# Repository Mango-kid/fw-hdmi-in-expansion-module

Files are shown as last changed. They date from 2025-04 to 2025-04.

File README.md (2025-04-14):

# Description
An HDMI input expansion module for the FW laptop. It utalizes the MS213x. As far as I can tell this is the highest preformance HDMI capture chip avalible that can fit in this package and not require serious thermal considerations. 
- USB3.0
- 100ms or better latency at 1080 in MJPEG mode (glass to glass, capture only will be less)

## Status
- hardware being prototyped and tested

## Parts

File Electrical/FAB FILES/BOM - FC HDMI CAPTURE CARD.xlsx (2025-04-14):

Designator | Qnty | Comment | Footprint | LCSC Part # | Externally Sourced | REMARK
C1,C2,C3,C4,C5,C6,C7,C8,C9,C10,C11,C12,C13,C14,C15,C16,C17,C18,C19,C20,C21,C22,C23,C27,C28,C29 | 26 | 0.1uF | 402
C24,C25 | 2 | 22pF | 402
C26 | 1 | 10uF | 603
C30,C31,C32,C33,C35,C36 | 6 | 22uF | 805 | C45783
C34 | 1 | 1uF | 603
D1 | 1 | LED | 402
D2 | 1 | PMEG1030EH | SOD-123F | C552800
J1 | 1 | HD06-19-RVS-MSMT-TR | HD06-19-RVS-MSMT-TR |  | HD06-19-RVS-MSMT-TR
J2 | 1 | USB-307HE-B-SU | SMD | C309351
L1,L2,L3 | 3 | 2.2uH | 1008 | C36400
R1,R2 | 2 | 4.7k | 402
R3 | 1 | 1.6k | 402
R4 | 1 | 0R | 402
R5 | 1 | 2k | 402
R6 | 1 | 200R | 402
R7,R8 | 2 | 1k | 402
R9 | 1 | 5.1k | 402
R10 | 1 | 100k | 402
R11 | 1 | 680k | 402
R12,R13,R16 | 3 | 150k | 402
R14 | 1 | 470k | 402
R15 | 1 | 180k | 402
U1 | 1 | MS2130 | QFN-64-EP(9x9) | C5905137
U2,U3,U4,U5 | 4 | TPD4E02B04DQA | USON-10(1x2.5) | C106794
U6 | 1 | EA3059 | QFN-24-EP(4x4) | C111586
U8 | 1 | W25Q16JVUXIQ | USON-8-EP(2x3) | C2843335
Y1 | 1 | Q22FA12800489 | Crystal:Crystal_SMD_2016-4Pin_2.0x1.6mm | C255882

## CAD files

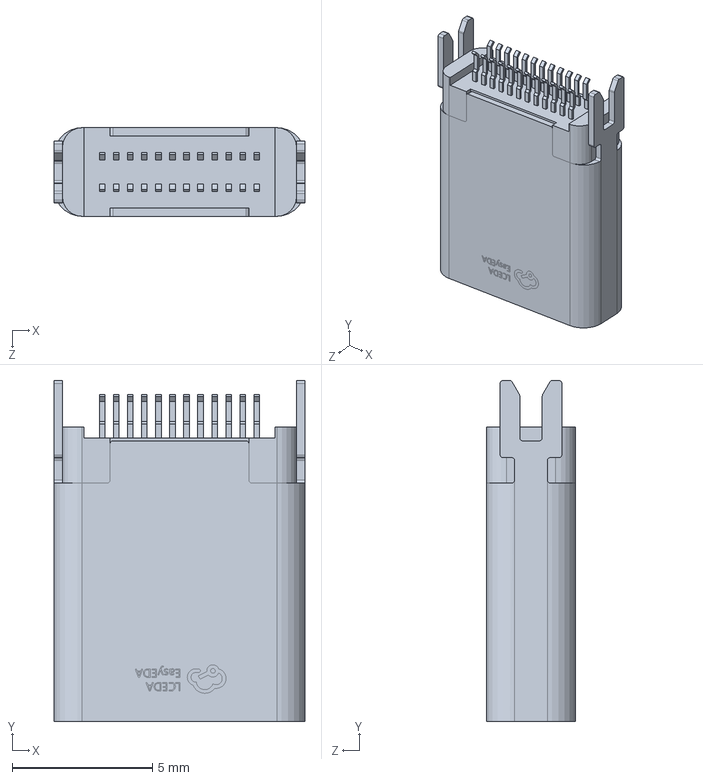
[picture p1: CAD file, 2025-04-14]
Electrical/FOOTPRINTS/3D MODELS/3D_PCB1_2025-03-29.step.SLDASM
8.94 x 12.2 x 3.16 mm

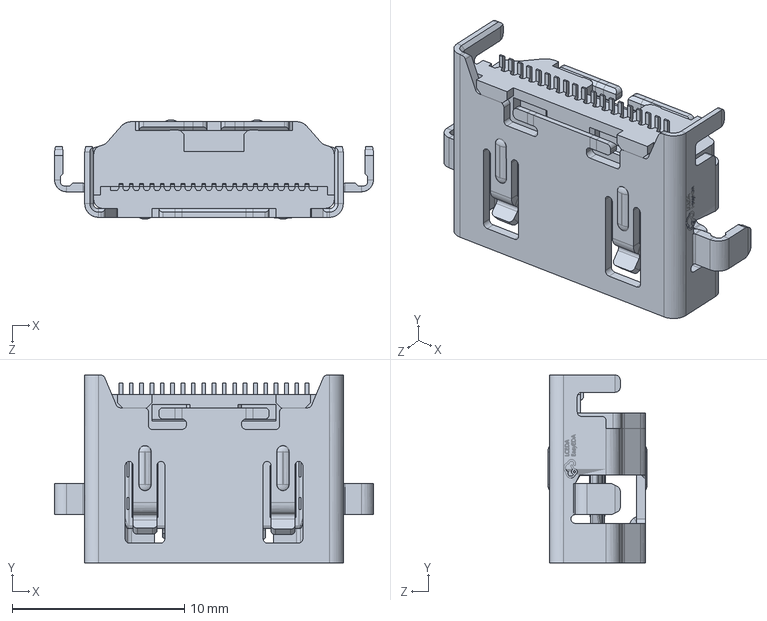
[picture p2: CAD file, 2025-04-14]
Electrical/FOOTPRINTS/3D MODELS/3D_PCB1_2025-03-29(2).step.SLDASM
18.5 x 10.9 x 5.75 mm

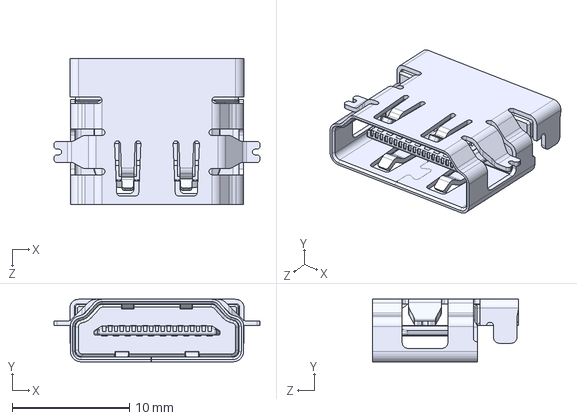
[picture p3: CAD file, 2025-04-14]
Electrical/FOOTPRINTS/3D MODELS/Same_Sky_HD06-19-RVS-MSMT-TR.step
17.6 x 5.36 x 12.5 mm

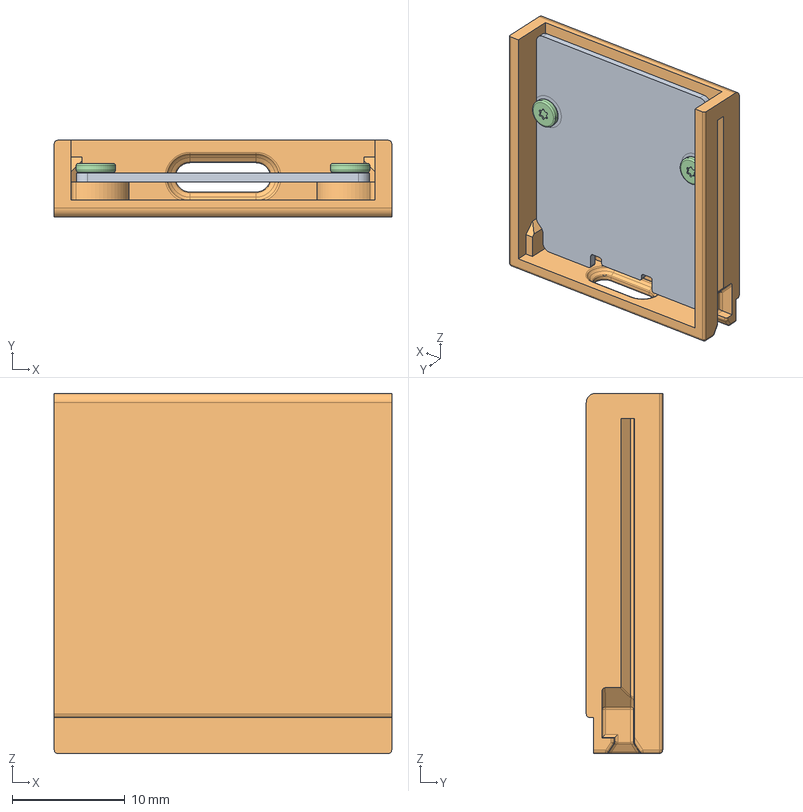
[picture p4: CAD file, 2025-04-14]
Electrical/FOOTPRINTS/3D MODELS/ExpansionCard_ThreadedInsert.stp
30.0 x 6.80 x 32.0 mm
FW_EXP_1USBC_FRAME_CLIP_BC_229_
NUT_M2X1-6L_2 x 2
STAR_SCREW_M2X3L_298_2 x 2

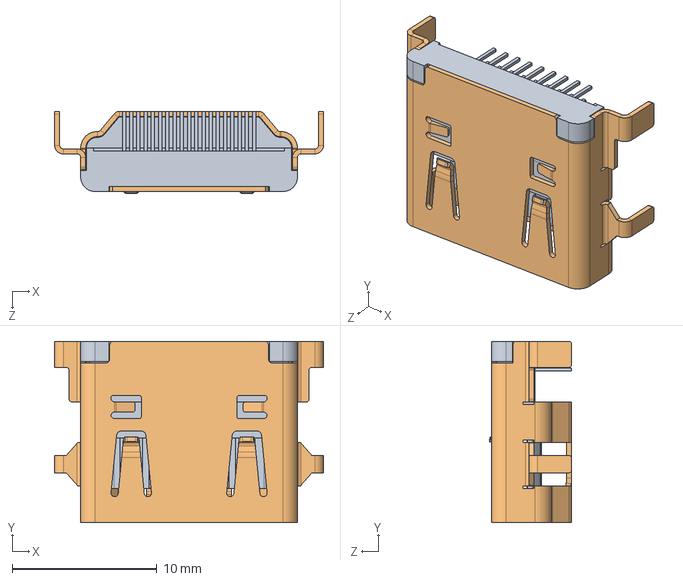
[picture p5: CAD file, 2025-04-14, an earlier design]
Electrical/FOOTPRINTS/3D MODELS/3D_PCB1_2025-03-29(1).STEP
18.6 x 12.5 x 5.70 mm

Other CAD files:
Electrical/FOOTPRINTS/3D MODELS/Board~sIiM.step.SLDPRT
Electrical/FOOTPRINTS/3D MODELS/3D_PCB1_2025-03-29.STEP
Electrical/FOOTPRINTS/3D MODELS/3D_PCB1_2025-03-29(2).STEP

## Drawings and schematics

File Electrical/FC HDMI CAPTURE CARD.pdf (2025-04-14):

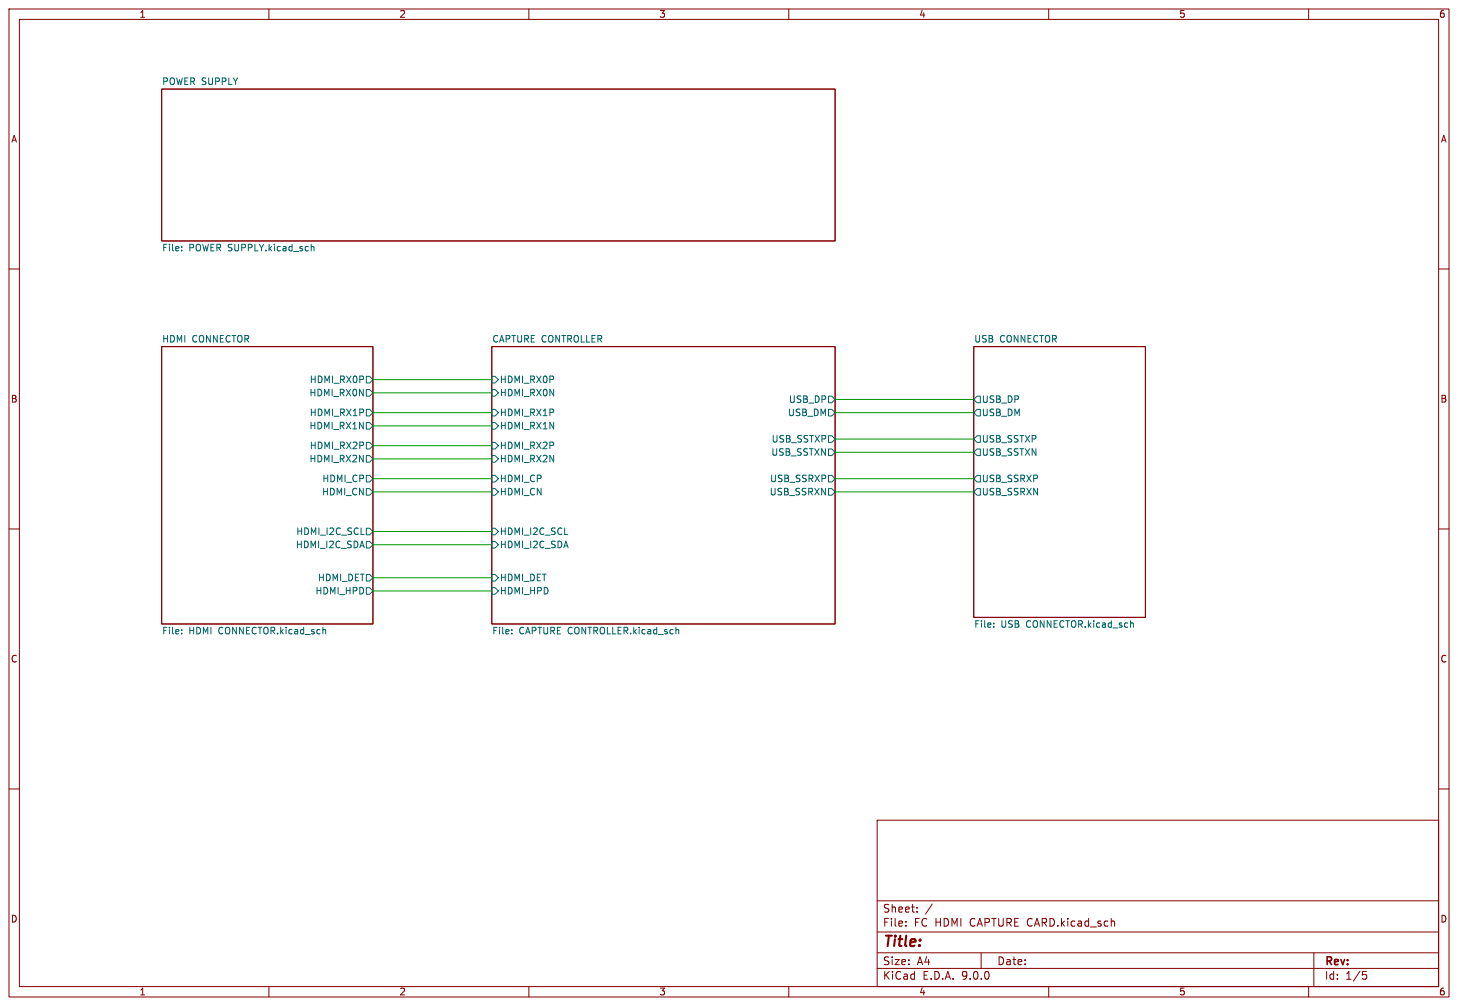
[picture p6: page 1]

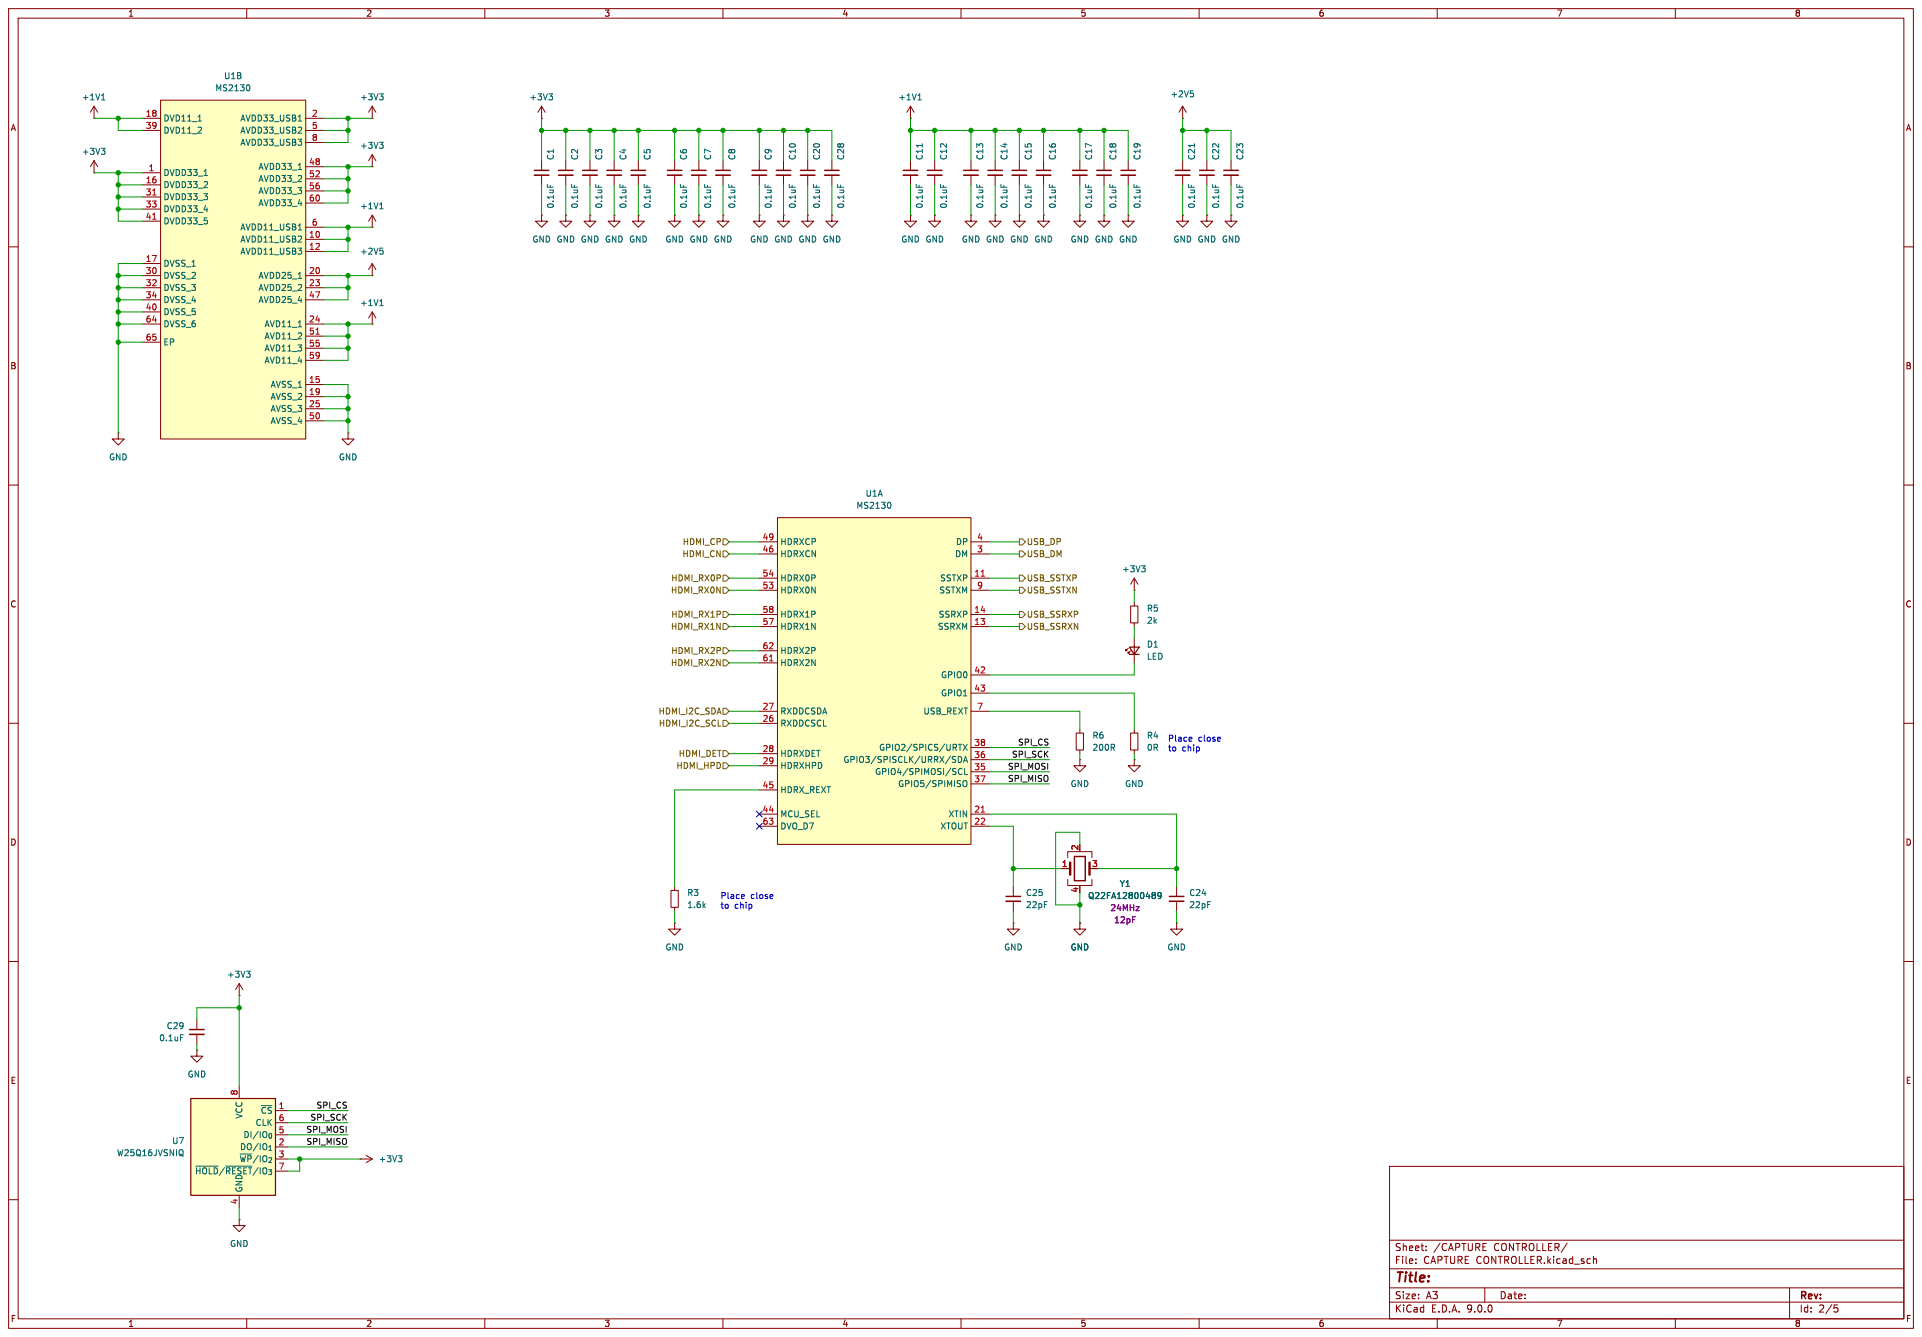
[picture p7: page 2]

to chip Place close

~{CS}1 CLK 6 DI/IO_{0}5 DO/IO_{1}2 ~{WP}/IO_{2} 3 ~{HOLD}/~{RESET}/IO_{3} 7 VCC

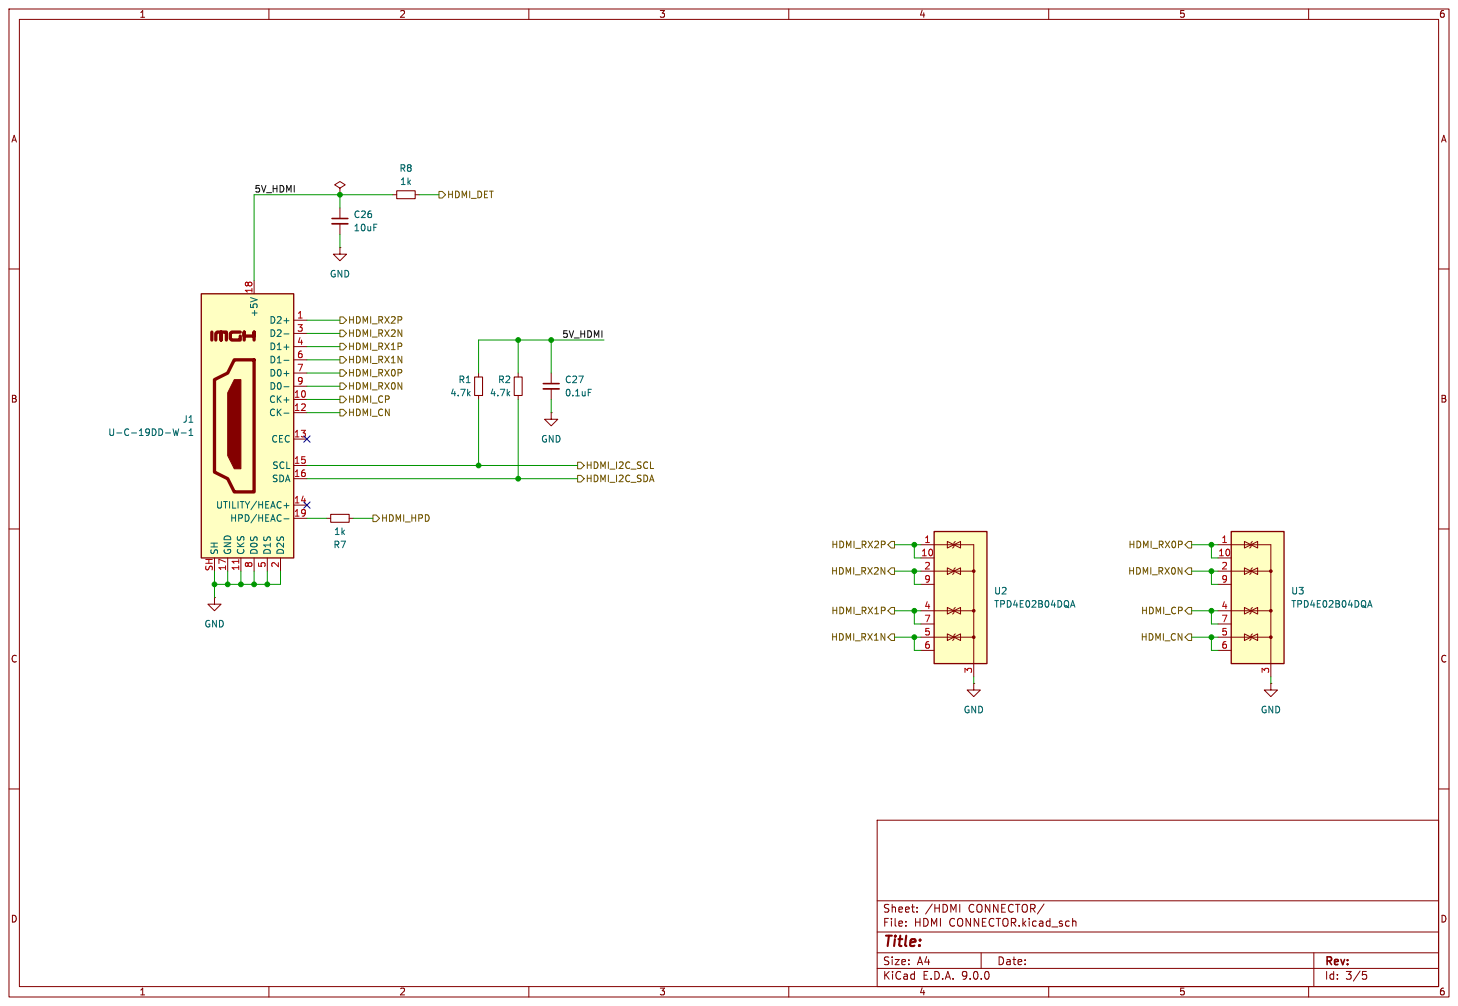
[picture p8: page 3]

8 CKS 11 GND 17 SH SH

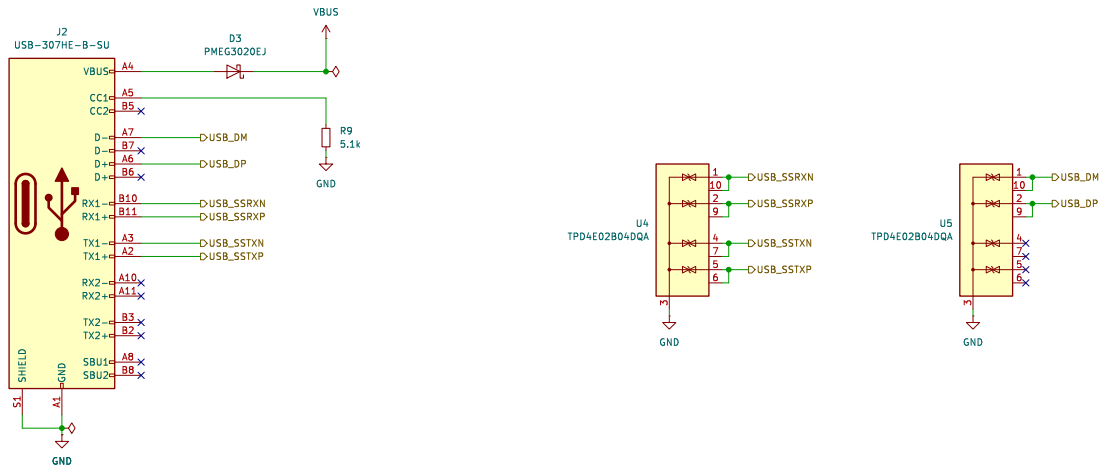
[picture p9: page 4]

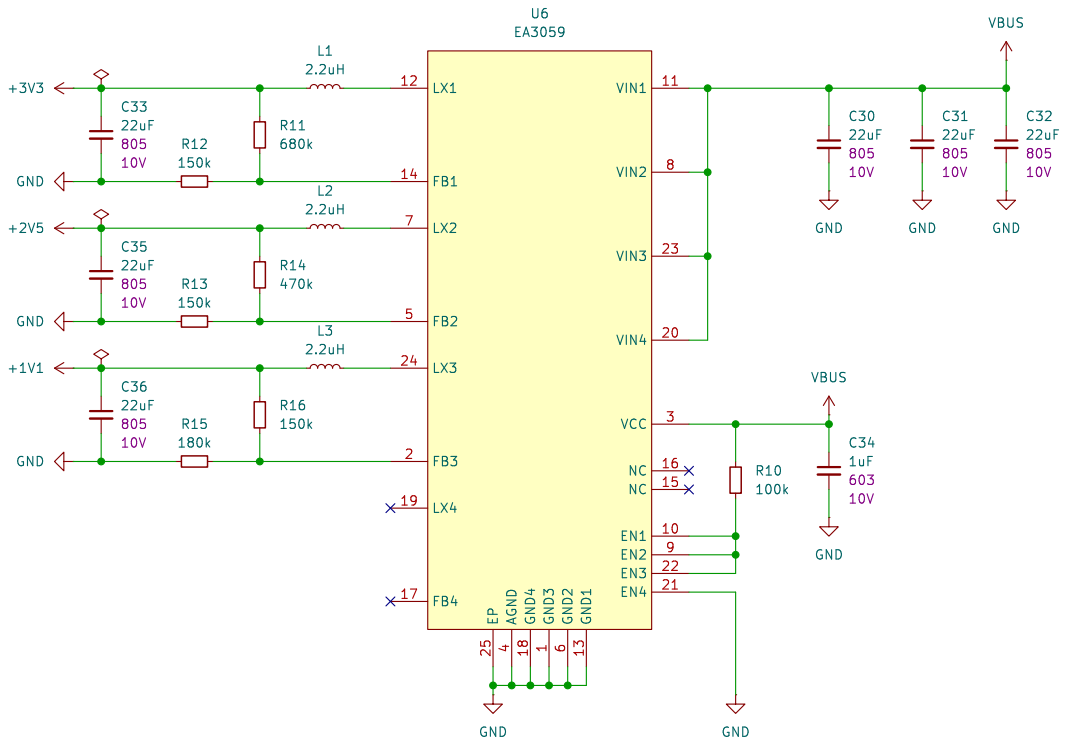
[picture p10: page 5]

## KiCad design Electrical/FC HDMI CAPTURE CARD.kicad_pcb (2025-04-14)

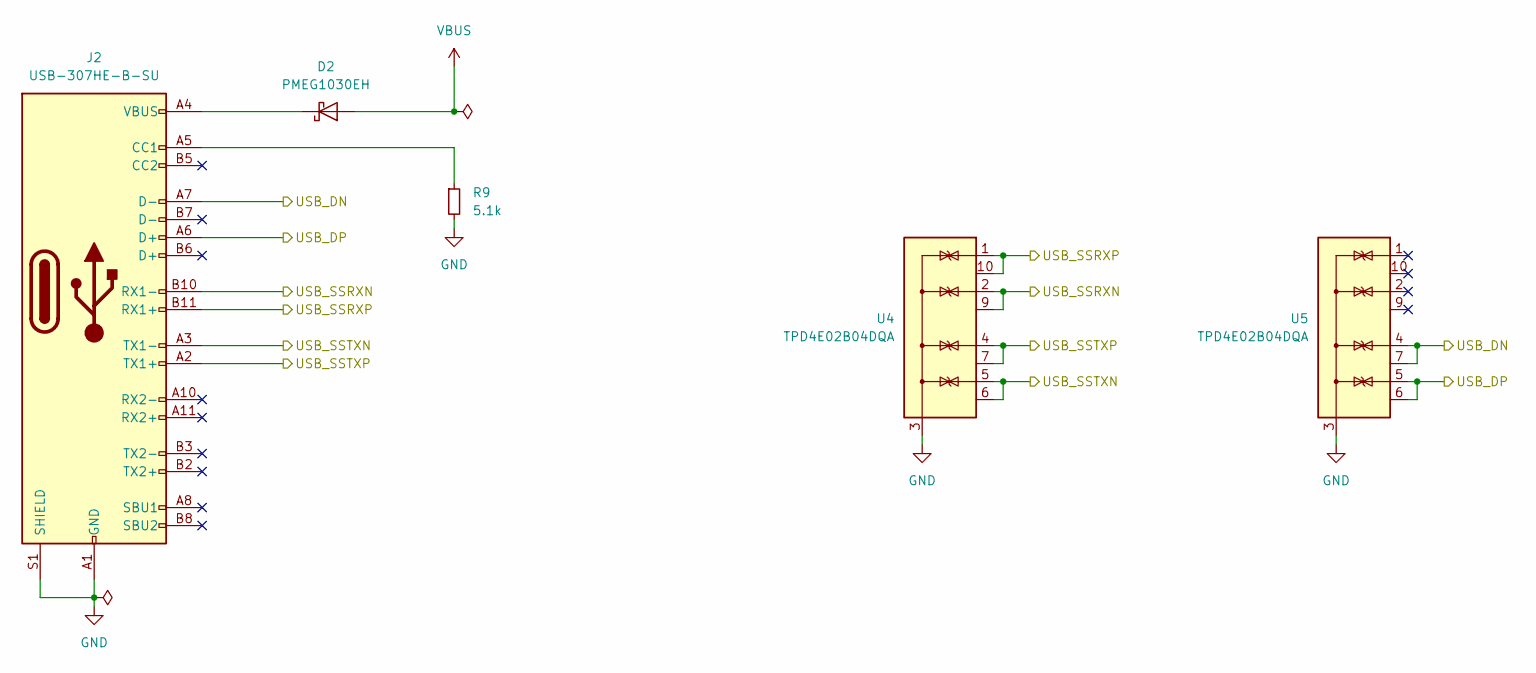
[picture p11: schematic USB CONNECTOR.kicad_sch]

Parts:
D2: PMEG1030EH; D_SOD-123F
J2: USB-307HE-B-SU; USB-TYPE-C-SMD_USB-307HE-B-SU
R9: 5.1k; R_0402_1005Metric
U4, U5: TPD4E02B04DQA; USON-10_2.5x1.0mm_P0.5mm

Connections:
/CAPTURE CONTROLLER/USB_DN: J2.A7 (D-), U5.4 (IO3), U5.7 (NC); also elsewhere on the board
/CAPTURE CONTROLLER/USB_DP: J2.A6 (D+), U5.5 (IO4), U5.6 (NC); also elsewhere on the board
/CAPTURE CONTROLLER/USB_SSRXN: J2.B10 (RX1-), U4.2 (IO2), U4.9 (NC); also elsewhere on the board
/CAPTURE CONTROLLER/USB_SSRXP: J2.B11 (RX1+), U4.1 (IO1), U4.10 (NC); also elsewhere on the board
/CAPTURE CONTROLLER/USB_SSTXN: J2.A3 (TX1-), U4.5 (IO4), U4.6 (NC); also elsewhere on the board
/CAPTURE CONTROLLER/USB_SSTXP: J2.A2 (TX1+), U4.4 (IO3), U4.7 (NC); also elsewhere on the board
GND: J2.A1 (GND), J2.A12 (GND), J2.B1 (GND), J2.B12 (GND), J2.S1 (SHIELD), R9.2, U4.3 (G), U4.8 (G), U5.3 (G), U5.8 (G); also elsewhere on the board
unnamed: D2.1 (K), J2.A4 (VBUS), J2.A9 (VBUS), J2.B4 (VBUS), J2.B9 (VBUS)
unnamed: J2.A5 (CC1), R9.1
VBUS: D2.2 (A); also elsewhere on the board

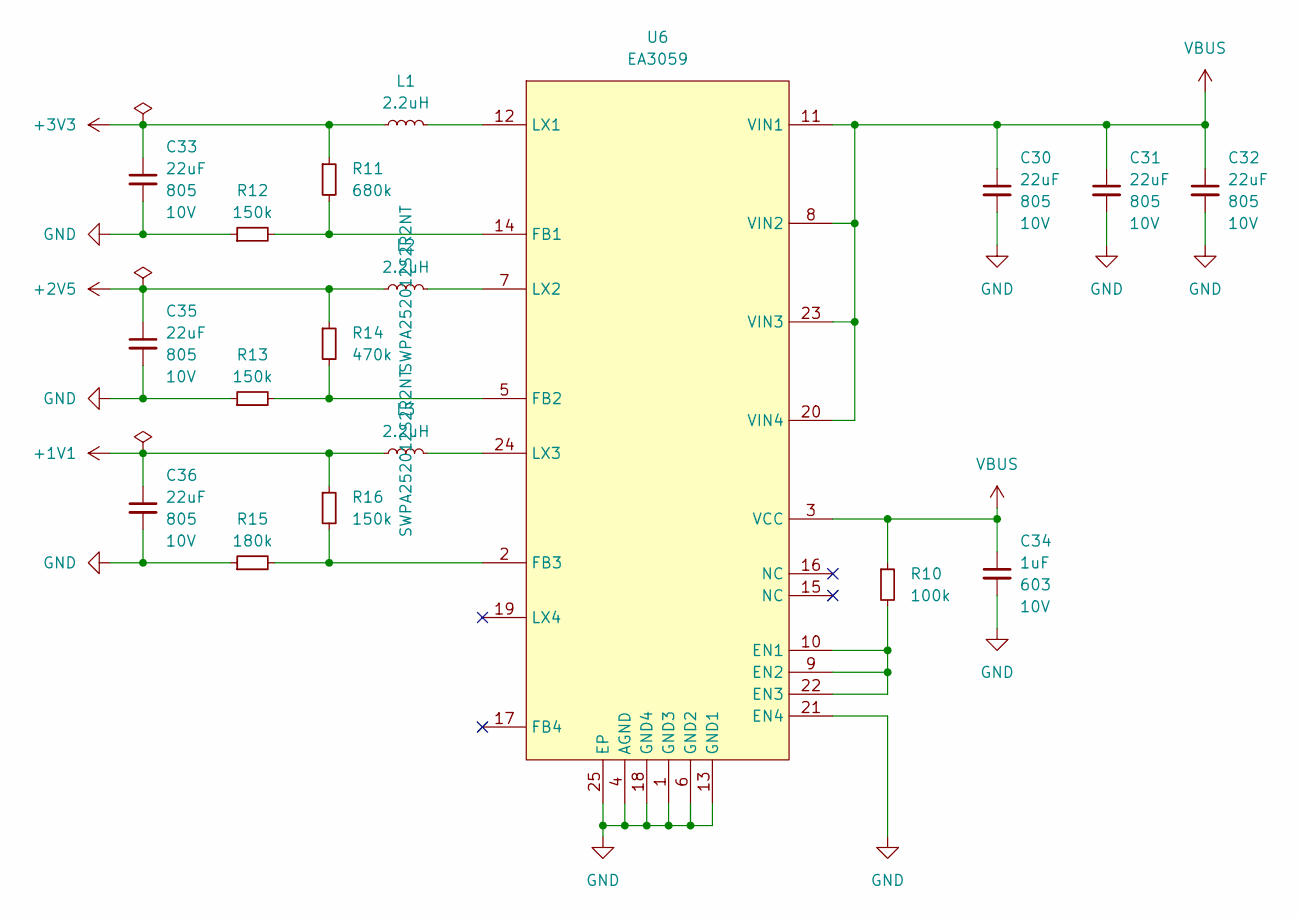
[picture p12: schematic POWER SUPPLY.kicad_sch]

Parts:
C30, C31, C32, C33, C35, C36: 22uF; C_0805_2012Metric; VOLTAGE 10V
C34: 1uF; C_0603_1608Metric; VOLTAGE 10V
L1, L2, L3: 2.2uH; L_1008_2520Metric; MPN SWPA252012S2R2NT
R10: 100k; R_0402_1005Metric
R11: 680k; R_0402_1005Metric
R12, R13, R16: 150k; R_0402_1005Metric
R14: 470k; R_0402_1005Metric
R15: 180k; R_0402_1005Metric
U6: EA3059; QFN-24-1EP_4x4mm_P0.5mm_EP2.5x2.5mm

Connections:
+1V1: C36.1, L3.1, R16.1; also elsewhere on the board
+2V5: C35.1, L2.1, R14.1; also elsewhere on the board
+3V3: C33.1, L1.1, R11.1; also elsewhere on the board
GND: C30.2, C31.2, C32.2, C33.2, C34.2, C35.2, C36.2, R12.1, R13.1, R15.1, U6.1 (GND3), U6.4 (AGND), U6.6 (GND2), U6.13 (GND1), U6.18 (GND4), U6.21 (EN4), U6.25 (EP); also elsewhere on the board
unnamed: R10.2, U6.9 (EN2), U6.10 (EN1), U6.22 (EN3)
unnamed: R11.2, R12.2, U6.14 (FB1)
unnamed: R13.2, R14.2, U6.5 (FB2)
unnamed: R15.2, R16.2, U6.2 (FB3)
unnamed: L1.2, U6.12 (LX1)
unnamed: L2.2, U6.7 (LX2)
unnamed: L3.2, U6.24 (LX3)
VBUS: C30.1, C31.1, C32.1, C34.1, R10.1, U6.3 (VCC), U6.8 (VIN2), U6.11 (VIN1), U6.20 (VIN4), U6.23 (VIN3); also elsewhere on the board

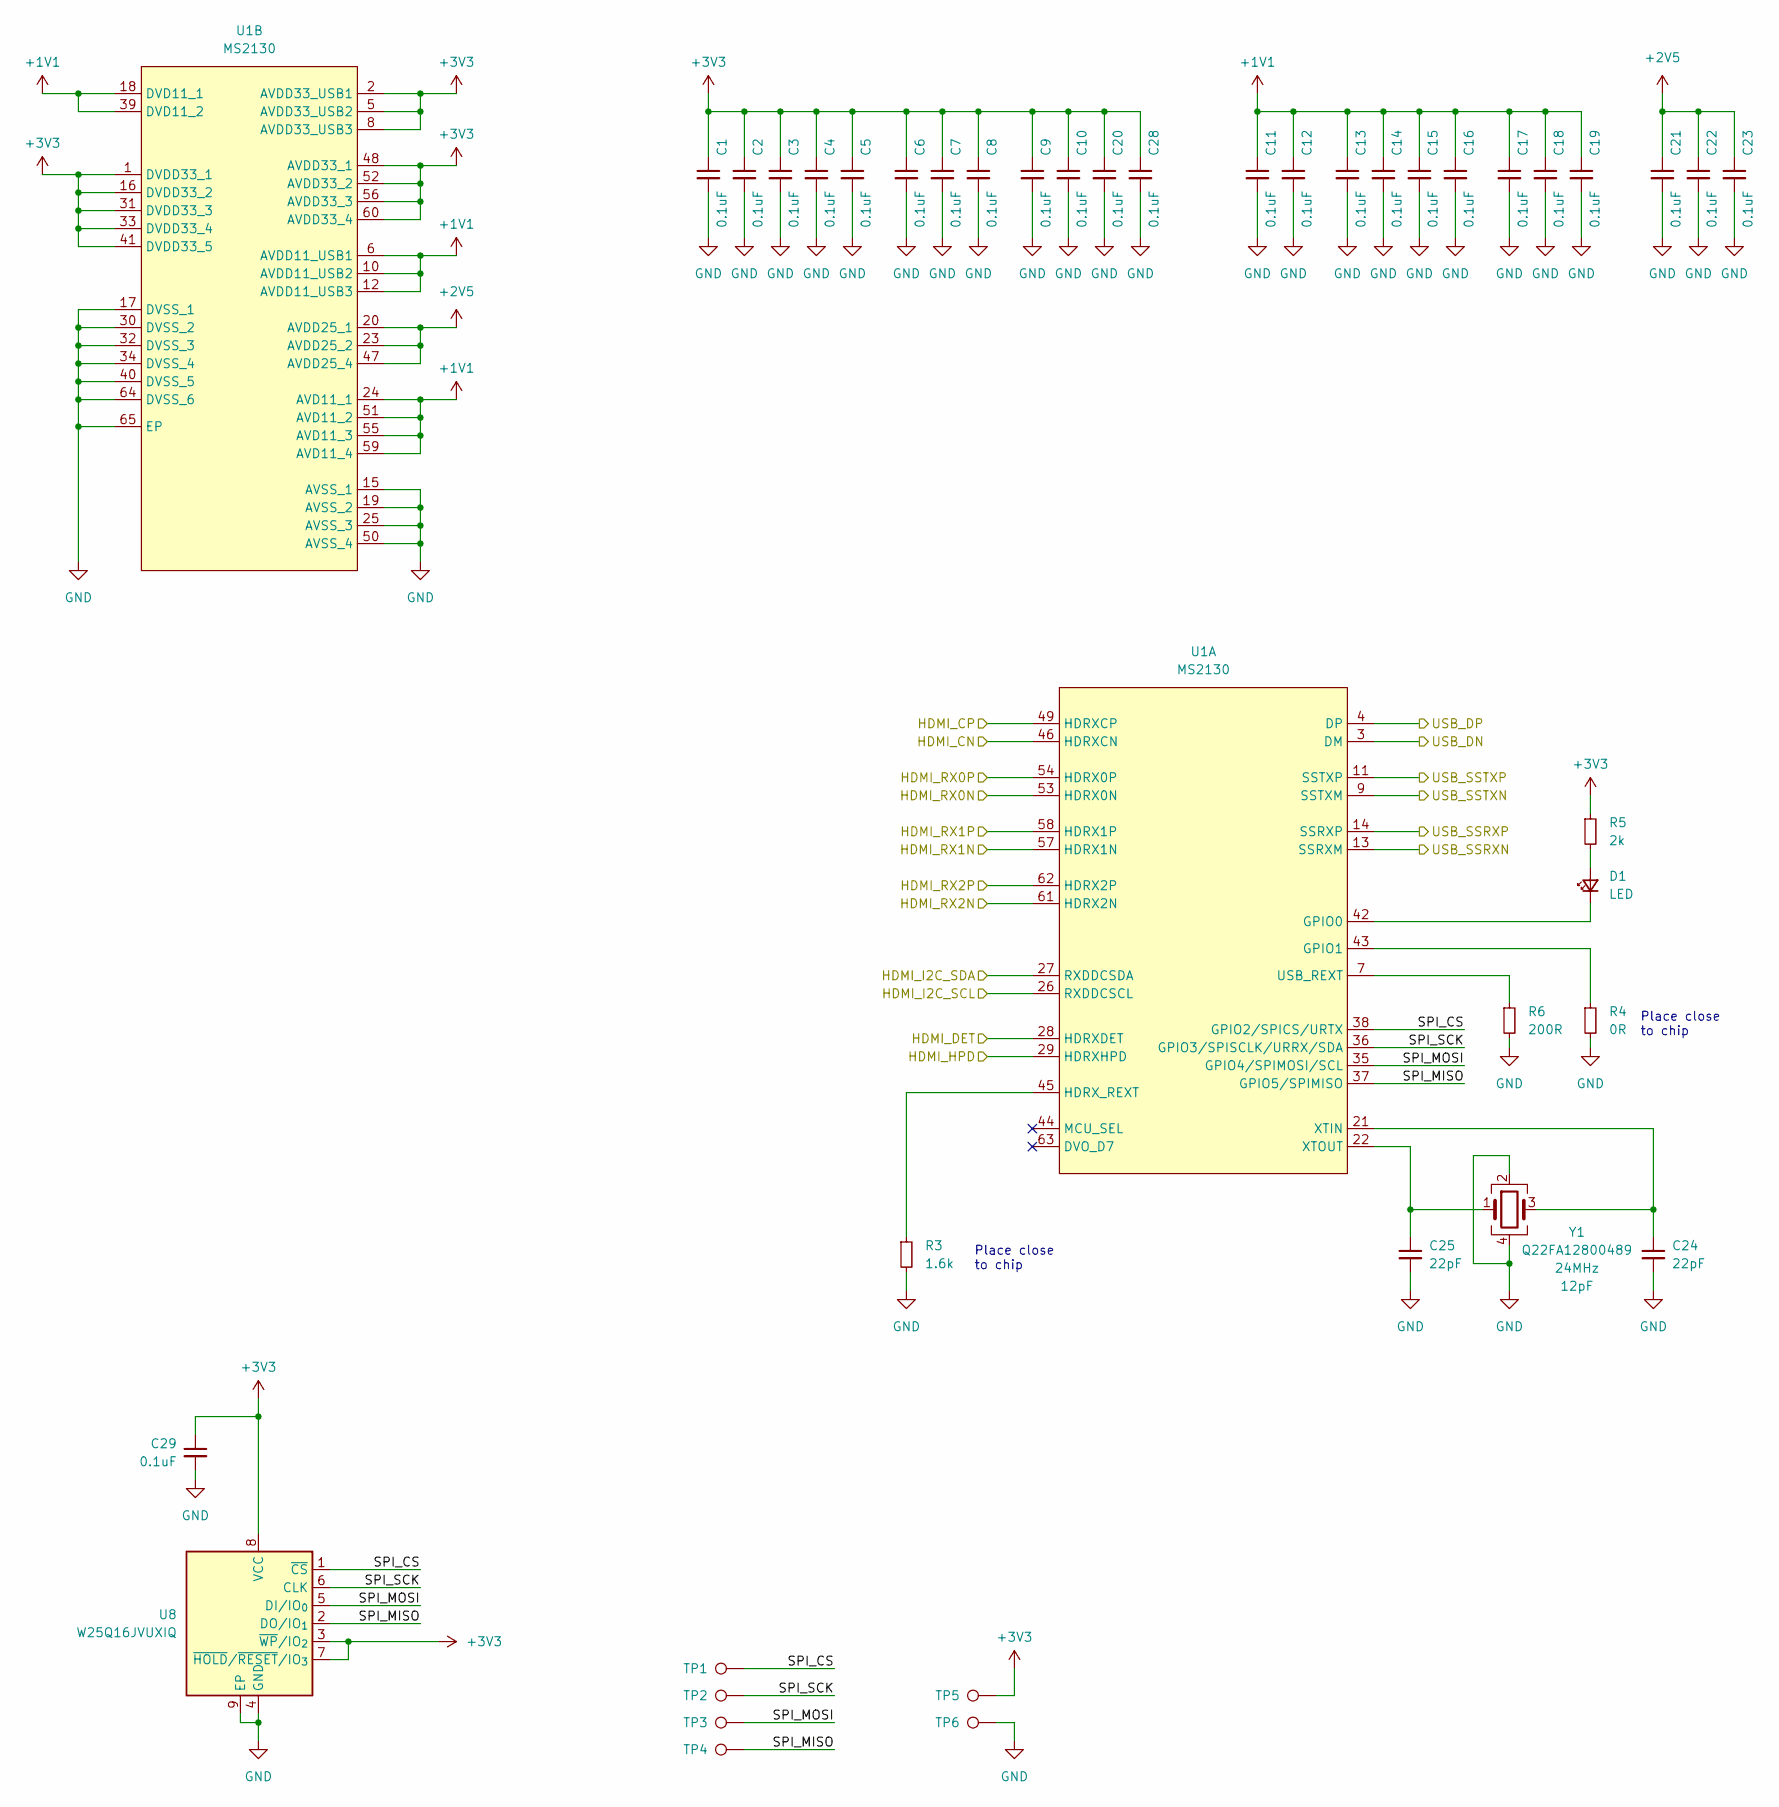
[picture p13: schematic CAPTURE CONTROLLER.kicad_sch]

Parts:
C1, C2, C3, C4, C5, C6, C7, C8, C9, C10, C11, C12, C13, C14, C15, C16, C17, C18, C19, C20, C21, C22, C23, C28, C29: 0.1uF; C_0402_1005Metric
C24, C25: 22pF; C_0402_1005Metric
D1: LED; LED_0402_1005Metric
R3: 1.6k; R_0402_1005Metric
R4: 0R; R_0402_1005Metric
R5: 2k; R_0402_1005Metric
R6: 200R; R_0402_1005Metric
TP1, TP2, TP3, TP4, TP5, TP6: TestPoint; TestPoint_Pad
U1: MS2130; QFN-64-1EP_9x9mm_P0.5mm_EP5.7x5.7mm
U8: W25Q16JVUXIQ; USON-8_L3.0-W2.0-P0.50-BL-EP
Y1: Q22FA12800489; Crystal_SMD_2016-4Pin_2.0x1.6mm

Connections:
+1V1: C11.1, C12.1, C13.1, C14.1, C15.1, C16.1, C17.1, C18.1, C19.1, U1.6 (AVDD11_USB1), U1.10 (AVDD11_USB2), U1.12 (AVDD11_USB3), U1.18 (DVD11_1), U1.24 (AVD11_1), U1.39 (DVD11_2), U1.51 (AVD11_2), U1.55 (AVD11_3), U1.59 (AVD11_4); also elsewhere on the board
+2V5: C21.1, C22.1, C23.1, U1.20 (AVDD25_1), U1.23 (AVDD25_2), U1.47 (AVDD25_4); also elsewhere on the board
+3V3: C1.1, C2.1, C3.1, C4.1, C5.1, C6.1, C7.1, C8.1, C9.1, C10.1, C20.1, C28.1, C29.1, R5.1, TP5.1, U1.1 (DVDD33_1), U1.2 (AVDD33_USB1), U1.5 (AVDD33_USB2), U1.8 (AVDD33_USB3), U1.16 (DVDD33_2), U1.31 (DVDD33_3), U1.33 (DVDD33_4), U1.41 (DVDD33_5), U1.48 (AVDD33_1), U1.52 (AVDD33_2), U1.56 (AVDD33_3), U1.60 (AVDD33_4), U8.3 (~WP/IO_{2}), U8.7 (~HOLD/~RESET/IO_{3}), U8.8 (VCC); also elsewhere on the board
/CAPTURE CONTROLLER/HDMI_CN: U1.46 (HDRXCN); also elsewhere on the board
/CAPTURE CONTROLLER/HDMI_CP: U1.49 (HDRXCP); also elsewhere on the board
/CAPTURE CONTROLLER/HDMI_DET: U1.28 (HDRXDET); also elsewhere on the board
/CAPTURE CONTROLLER/HDMI_HPD: U1.29 (HDRXHPD); also elsewhere on the board
/CAPTURE CONTROLLER/HDMI_I2C_SCL: U1.26 (RXDDCSCL); also elsewhere on the board
/CAPTURE CONTROLLER/HDMI_I2C_SDA: U1.27 (RXDDCSDA); also elsewhere on the board
/CAPTURE CONTROLLER/HDMI_RX0N: U1.53 (HDRX0N); also elsewhere on the board
/CAPTURE CONTROLLER/HDMI_RX0P: U1.54 (HDRX0P); also elsewhere on the board
/CAPTURE CONTROLLER/HDMI_RX1N: U1.57 (HDRX1N); also elsewhere on the board
/CAPTURE CONTROLLER/HDMI_RX1P: U1.58 (HDRX1P); also elsewhere on the board
/CAPTURE CONTROLLER/HDMI_RX2N: U1.61 (HDRX2N); also elsewhere on the board
/CAPTURE CONTROLLER/HDMI_RX2P: U1.62 (HDRX2P); also elsewhere on the board
/CAPTURE CONTROLLER/SPI_CS: TP1.1, U1.38 (GPIO2/SPICS/URTX), U8.1 (~CS)
/CAPTURE CONTROLLER/SPI_MISO: TP4.1, U1.37 (GPIO5/SPIMISO), U8.2 (DO/IO_{1})
/CAPTURE CONTROLLER/SPI_MOSI: TP3.1, U1.35 (GPIO4/SPIMOSI/SCL), U8.5 (DI/IO_{0})
/CAPTURE CONTROLLER/SPI_SCK: TP2.1, U1.36 (GPIO3/SPISCLK/URRX/SDA), U8.6 (CLK)
/CAPTURE CONTROLLER/USB_DN: U1.3 (DM); also elsewhere on the board
/CAPTURE CONTROLLER/USB_DP: U1.4 (DP); also elsewhere on the board
/CAPTURE CONTROLLER/USB_SSRXN: U1.13 (SSRXM); also elsewhere on the board
/CAPTURE CONTROLLER/USB_SSRXP: U1.14 (SSRXP); also elsewhere on the board
/CAPTURE CONTROLLER/USB_SSTXN: U1.9 (SSTXM); also elsewhere on the board
/CAPTURE CONTROLLER/USB_SSTXP: U1.11 (SSTXP); also elsewhere on the board
GND: C1.2, C2.2, C3.2, C4.2, C5.2, C6.2, C7.2, C8.2, C9.2, C10.2, C11.2, C12.2, C13.2, C14.2, C15.2, C16.2, C17.2, C18.2, C19.2, C20.2, C21.2, C22.2, C23.2, C24.2, C25.2, C28.2, C29.2, R3.2, R4.2, R6.2, TP6.1, U1.15 (AVSS_1), U1.17 (DVSS_1), U1.19 (AVSS_2), U1.25 (AVSS_3), U1.30 (DVSS_2), U1.32 (DVSS_3), U1.34 (DVSS_4), U1.40 (DVSS_5), U1.50 (AVSS_4), U1.64 (DVSS_6), U1.65 (EP), U8.4 (GND), U8.9 (EP), Y1.2, Y1.4; also elsewhere on the board
unnamed: D1.2 (A), R5.2
unnamed: D1.1 (K), U1.42 (GPIO0)
unnamed: R4.1, U1.43 (GPIO1)
unnamed: R3.1, U1.45 (HDRX_REXT)
unnamed: R6.1, U1.7 (USB_REXT)
unnamed: C24.1, U1.21 (XTIN), Y1.3
unnamed: C25.1, U1.22 (XTOUT), Y1.1

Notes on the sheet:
Place close to chip

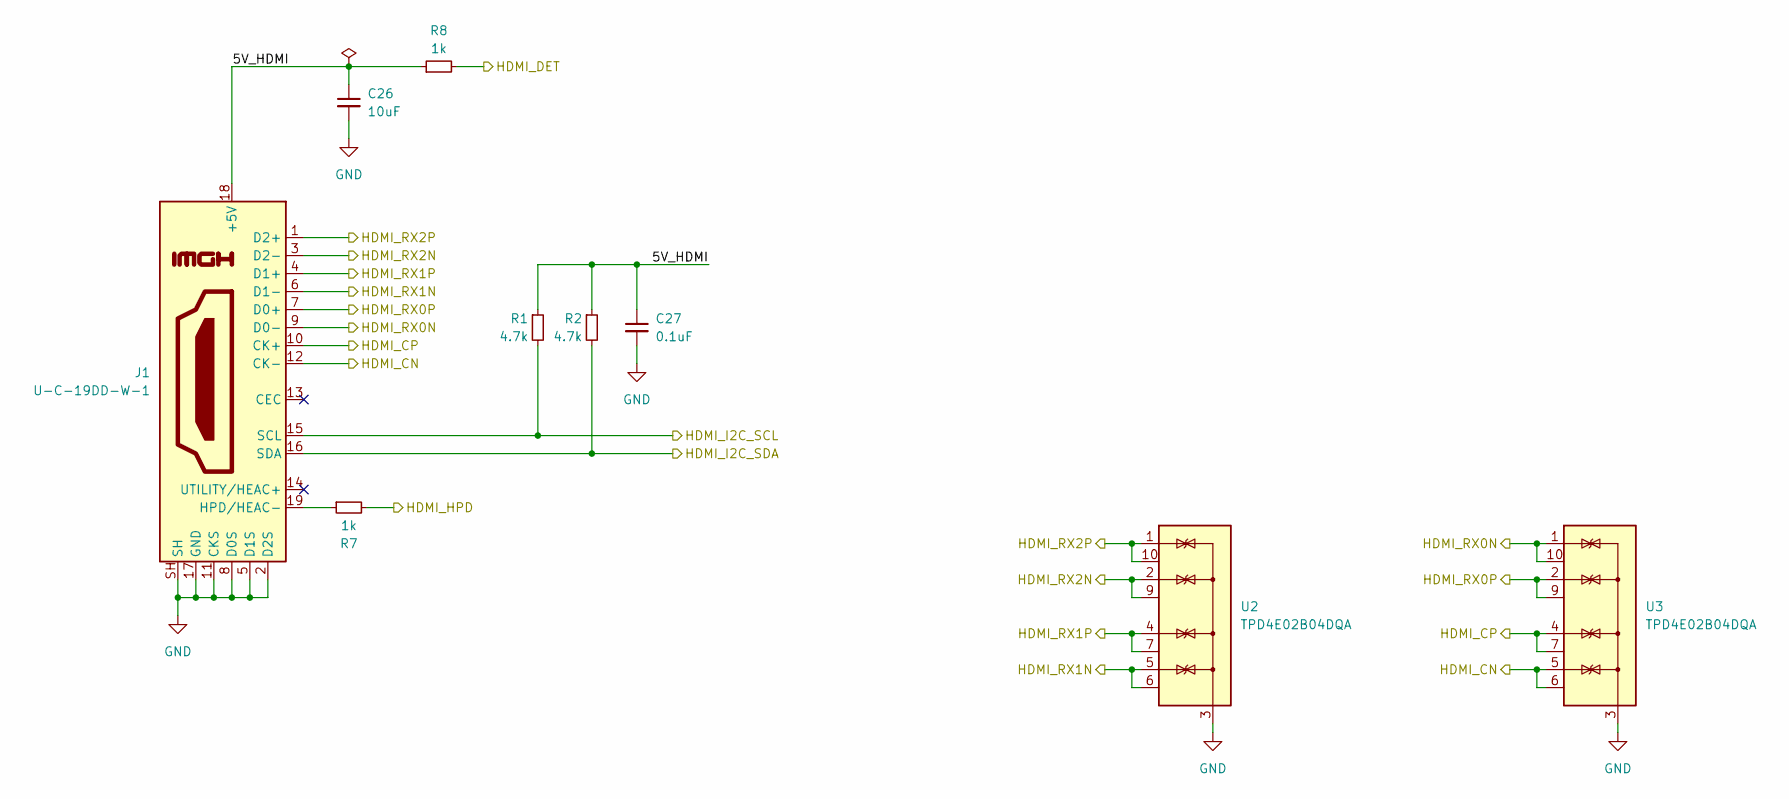
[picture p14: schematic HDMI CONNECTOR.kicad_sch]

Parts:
C26: 10uF; C_0603_1608Metric
C27: 0.1uF; C_0402_1005Metric
J1: U-C-19DD-W-1; SAMESKY_HD06-19-RVS-MSMT-TR
R1, R2: 4.7k; R_0402_1005Metric
R7, R8: 1k; R_0402_1005Metric
U2, U3: TPD4E02B04DQA; USON-10_2.5x1.0mm_P0.5mm

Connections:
/CAPTURE CONTROLLER/HDMI_CN: J1.12 (CK-), U3.5 (IO4), U3.6 (NC); also elsewhere on the board
/CAPTURE CONTROLLER/HDMI_CP: J1.10 (CK+), U3.4 (IO3), U3.7 (NC); also elsewhere on the board
/CAPTURE CONTROLLER/HDMI_DET: R8.2; also elsewhere on the board
/CAPTURE CONTROLLER/HDMI_HPD: R7.2; also elsewhere on the board
/CAPTURE CONTROLLER/HDMI_I2C_SCL: J1.15 (SCL), R1.2; also elsewhere on the board
/CAPTURE CONTROLLER/HDMI_I2C_SDA: J1.16 (SDA), R2.2; also elsewhere on the board
/CAPTURE CONTROLLER/HDMI_RX0N: J1.9 (D0-), U3.1 (IO1), U3.10 (NC); also elsewhere on the board
/CAPTURE CONTROLLER/HDMI_RX0P: J1.7 (D0+), U3.2 (IO2), U3.9 (NC); also elsewhere on the board
/CAPTURE CONTROLLER/HDMI_RX1N: J1.6 (D1-), U2.5 (IO4), U2.6 (NC); also elsewhere on the board
/CAPTURE CONTROLLER/HDMI_RX1P: J1.4 (D1+), U2.4 (IO3), U2.7 (NC); also elsewhere on the board
/CAPTURE CONTROLLER/HDMI_RX2N: J1.3 (D2-), U2.2 (IO2), U2.9 (NC); also elsewhere on the board
/CAPTURE CONTROLLER/HDMI_RX2P: J1.1 (D2+), U2.1 (IO1), U2.10 (NC); also elsewhere on the board
/HDMI CONNECTOR/5V_HDMI: C26.1, C27.1, J1.18 (+5V), R1.1, R2.1, R8.1
GND: C26.2, C27.2, J1.2 (D2S), J1.5 (D1S), J1.8 (D0S), J1.11 (CKS), J1.17 (GND), J1.SH, U2.3 (G), U2.8 (G), U3.3 (G), U3.8 (G); also elsewhere on the board
unnamed: J1.19 (HPD/HEAC-), R7.1

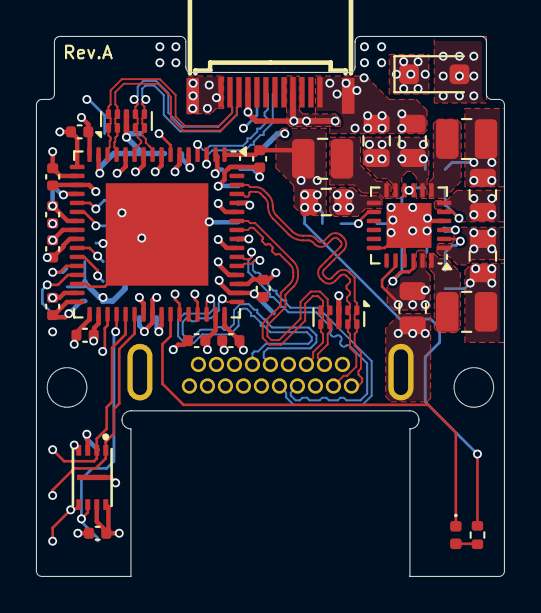
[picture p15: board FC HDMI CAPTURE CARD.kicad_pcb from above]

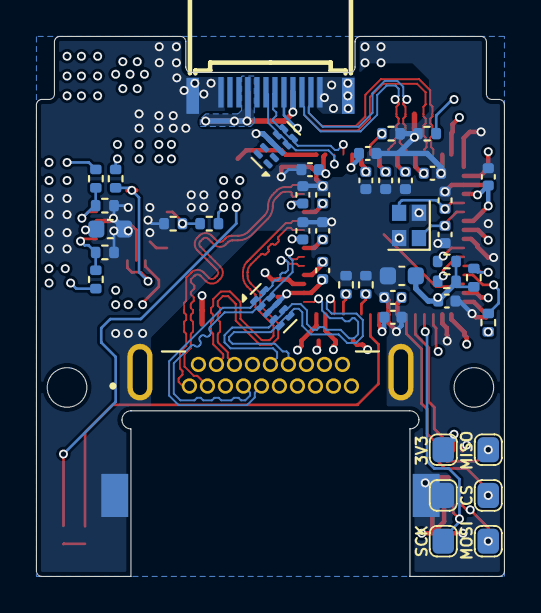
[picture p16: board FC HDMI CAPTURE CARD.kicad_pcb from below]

Board: 6 copper layers, 26.0 x 30.0 mm, 75 parts (44 on the bottom side), 45 nets.

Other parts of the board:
H1, H2: MountingHole; MountingHole_2.2mm_M2
